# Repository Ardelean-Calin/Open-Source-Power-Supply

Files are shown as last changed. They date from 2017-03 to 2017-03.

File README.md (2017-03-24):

# Open-Source-Power-Supply
An open source benchtop power supply that's good enough for most purposes.

The case was **3D printed** using a [Monoprice Select Mini](https://www.monoprice.com/product?p_id=15365) with wood PLA
for the front and back panels and green PLA for the top and bottom parts of the case.

The 3D designs were generated using [Heartman's Ultimate Box Maker](http://www.thingiverse.com/thing:1264391) and 
[Steve Colley's Parametric Potentiometer Knob](http://www.thingiverse.com/thing:20513).

## Characteristics
- **Input Voltage:** Up to 19V without fan
- **Output Voltage:** 0-12V
- **Output Current:** 0-600mA (see Note)
- Adjustable current limit

**Note:** Current can go up to 800mA by replacing the five 10 Ohm resistors with five 5 Ohm resistors. One should also double the gain of the differential amplifier in this case, so as to display voltage and current correctly.

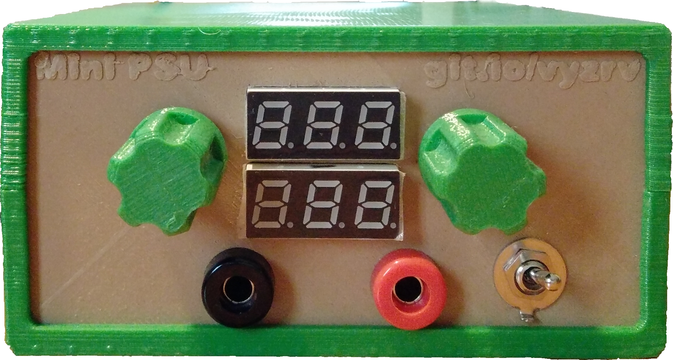
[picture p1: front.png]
Power Supply Front

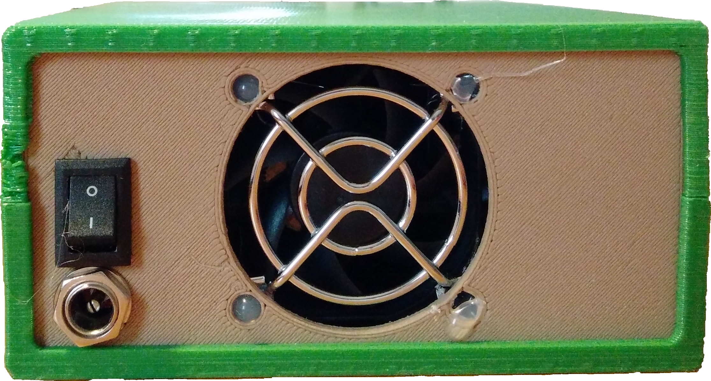
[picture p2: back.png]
Power Supply Back

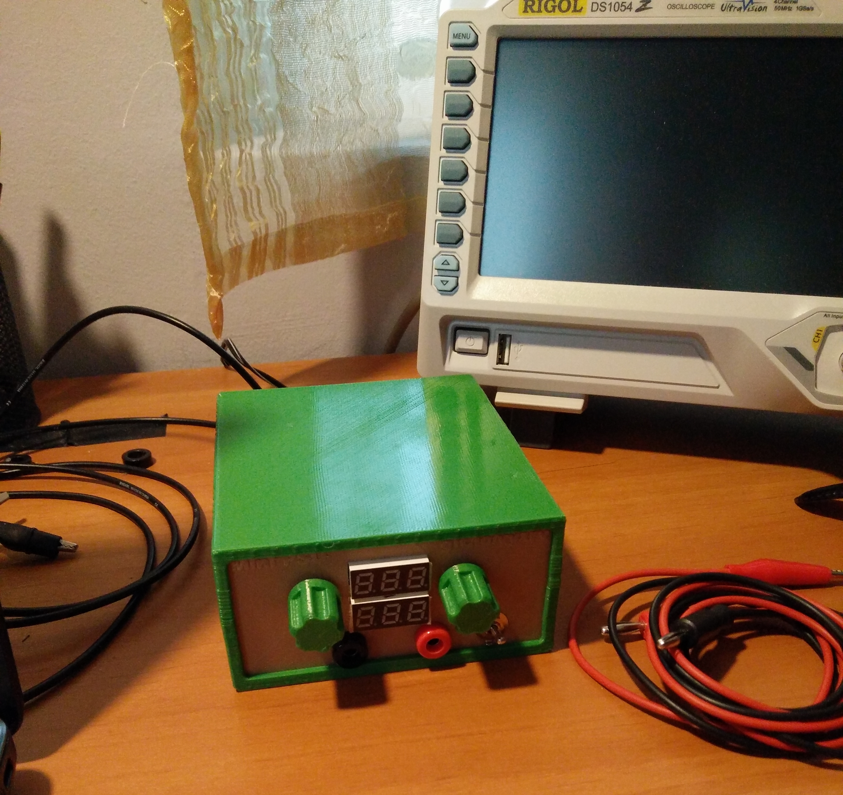
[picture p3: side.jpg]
Power Supply Side


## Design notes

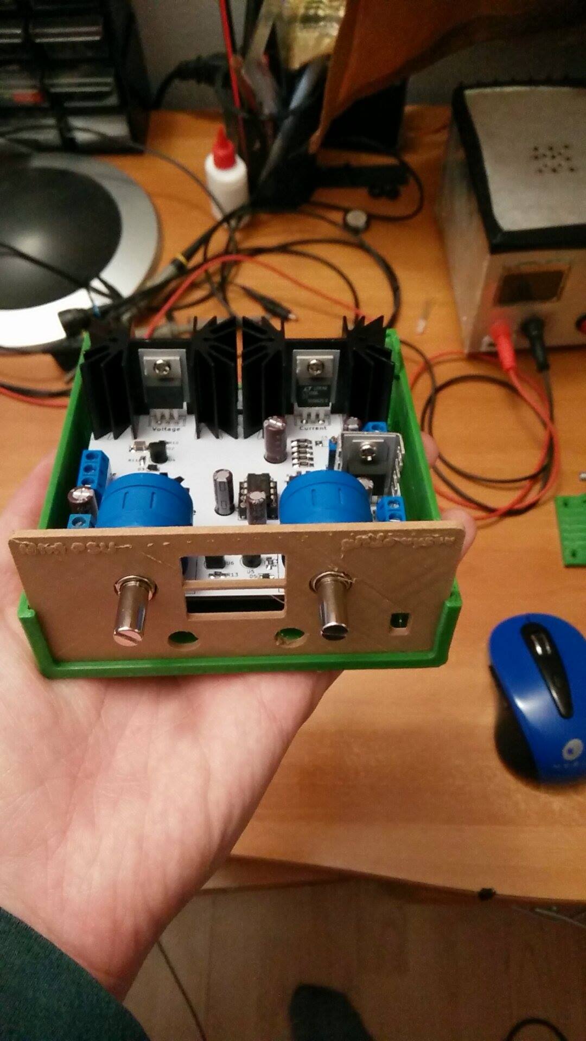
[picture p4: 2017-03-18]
inside.jpg

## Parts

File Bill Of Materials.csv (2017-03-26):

Id | Designator | Package | Quantity | Designation | Supplier and ref
1 | C1,C6,C7,C8 | CP_Radial_D5.0mm_P2.00mm | 4 | 10u
2 | C2 | CP_Radial_D6.3mm_P2.50mm | 1 | 47uF electro
3 | C3 | CP_Radial_D6.3mm_P2.50mm | 1 | 47u
4 | C4 | C_1210_HandSoldering | 1 | 4.7u
5 | C9 | C_0805_HandSoldering | 1 | 0.1u
6 | D1,D2,D3,D9,D10 | D_SOD-323_HandSoldering | 5 | 1N5819
7 | D4,D5,D6,D7,D8 | D_SOD-323_HandSoldering | 5 | 1N4448
8 | HS1,HS2 | Heatsink_Fischer_SK129-STS_42x25mm_2xDrill2.5mm | 2 | Heatsink
9 | HS3 | TO220-Small-16mmx8mm | 1 | Heatsink
10 | J1 | bornier2 | 1 | Input Voltage
11 | J2 | bornier2 | 1 | Output Voltage
12 | J3 | bornier3 | 1 | Voltage Meter
13 | J4 | bornier3 | 1 | Current Meter
14 | R1,R2 | R_0805_HandSoldering | 2 | 50k
15 | R3,R4 | R_0805_HandSoldering | 2 | 10k
16 | R10 | R_0805_HandSoldering | 1 | 1k
17 | R11,R13 | R_0805_HandSoldering | 2 | 15
18 | R12 | R_0805_HandSoldering | 1 | 33
19 | R14 | R_0805_HandSoldering | 1 | 330
20 | RV1 | Potentiometer_Trimmer_Bourns_3296W | 1 | 100 (multiturn)
21 | RV2,RV3 | Potentiometer-3596S-10k-Pot | 2 | 10k
22 | U1 | DIP-8_W7.62mm_Socket_LongPads | 1 | LT1013
23 | U2 | TO-220 | 1 | LT1086
24 | U3 | TO-220 | 1 | LM1117-ADJ
25 | U4,U5,U6 | TO-92_Inline_Narrow_Oval | 3 | LM334Z
26 | U7 | DIP-8_W7.62mm_Socket_LongPads | 1 | ICL7660
27 | U8 | TO-220 | 1 | LM7812CT
28 | R5,R6,R7,R8,R9 | R_1206_HandSoldering | 5 | 10
29 | HA40101V4-000U-999 | Fan: DC; axial; 12VDC; 40x40x10mm; 9m3/h; 18.2dBA | 1 | http://bit.ly/2nCJSI9
30 | R1-22-B | 4mm Banana Socket - Black | 1 | http://bit.ly/2nkKlNd
31 | R1-22-R | 4mm Banana Socket - Red | 1 | http://bit.ly/2n6f92k
32 | Voltmeter | Green Three line panel Voltmeter 0-100VDC | 2 | http://bit.ly/2n6a61O
33 | TSSM1022A1 | Switch: toggle; 2-position; SPDT; ON-ON; 1A/250VAC; Cutout: Ø5mm | 1 | http://bit.ly/2nCCyMR
34 | FG-04A | Fan guard 40mm | 1 | http://bit.ly/2nkV2z9
35 | RSSM1011C3BK | Rocker switch; 2-position; SPST; ON-OFF; 1A/250VAC | 1 | http://bit.ly/2nXvFq7
36 | DC socket. See back panel model |  | 1

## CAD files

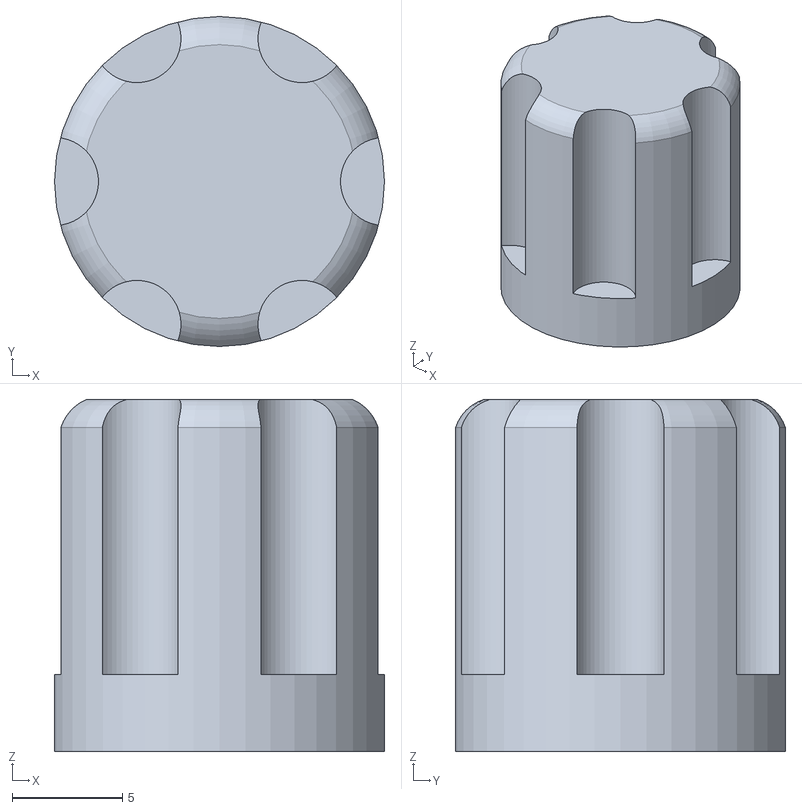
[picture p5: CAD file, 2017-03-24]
3D Printed Case/STLs/knob.stl
15.0 x 15.0 x 16.0

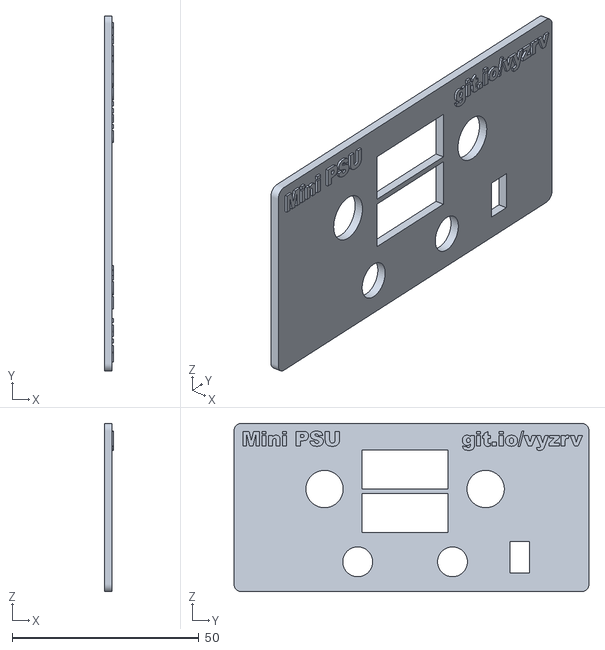
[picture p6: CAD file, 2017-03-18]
3D Printed Case/STLs/panel_front.stl
2.50 x 95.1 x 45.1

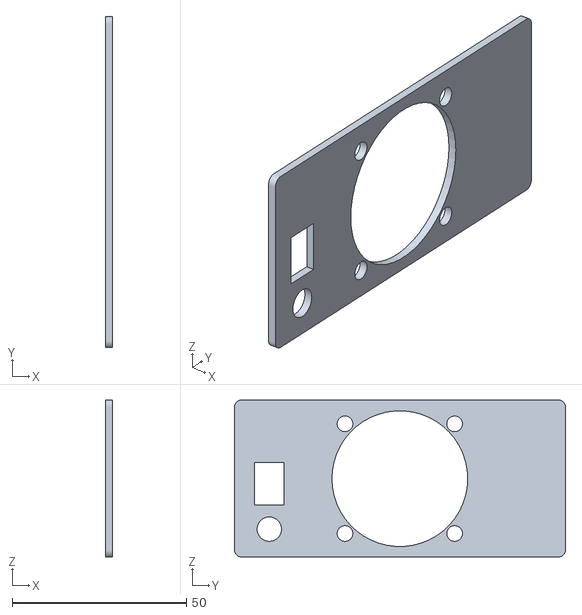
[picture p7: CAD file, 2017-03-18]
3D Printed Case/STLs/back_panel.stl
2.00 x 95.1 x 45.1

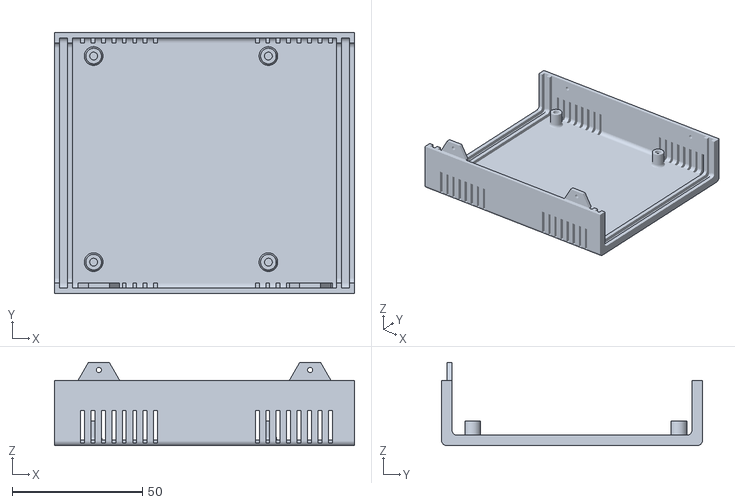
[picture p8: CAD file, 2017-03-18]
3D Printed Case/STLs/U_Box_Bottom.stl
115.0 x 100.0 x 31.9

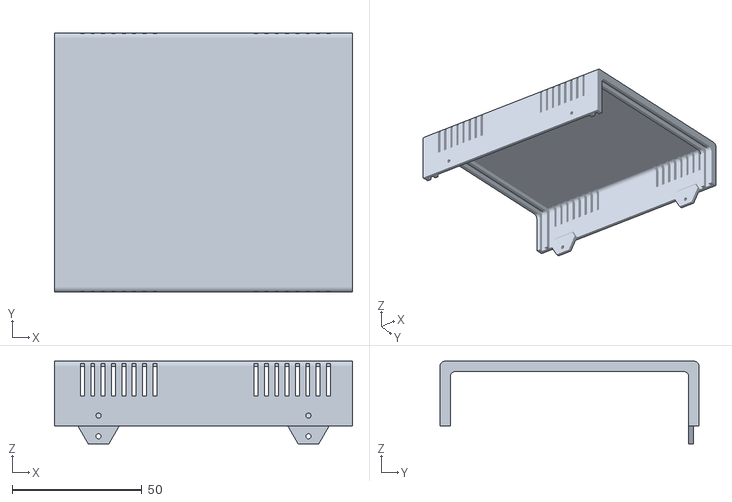
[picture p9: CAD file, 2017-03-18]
3D Printed Case/STLs/U_Box_Top.stl
115.0 x 100.0 x 31.9

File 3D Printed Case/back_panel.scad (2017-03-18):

/*//////////////////////////////////////////////////////////////////
              -    FB Aka Heartman/Hearty 2016     -                   
              -   http://heartygfx.blogspot.com    -                  
              -       OpenScad Parametric Box      -                     
              -         CC BY-NC 3.0 License       -                      
////////////////////////////////////////////////////////////////////                                                                                                             
12/02/2016 - Fixed minor bug 
28/02/2016 - Added holes ventilation option                    
09/03/2016 - Added PCB feet support, fixed the shell artefact on export mode. 

*/////////////////////////// - Info - //////////////////////////////

// All coordinates are starting as integrated circuit pins.
// From the top view :

//   CoordD           <---       CoordC
//                                 ^
//                                 ^
//                                 ^
//   CoordA           --->       CoordB


////////////////////////////////////////////////////////////////////


////////// - Paramètres de la boite - Box parameters - /////////////

/* [Box dimensions] */
// - Longueur - Length  
  Length        = 110;       
// - Largeur - Width
  Width         = 100;                     
// - Hauteur - Height  
  Height        = 50;  
// - Epaisseur - Wall thickness  
  Thick         = 2;//[2:5]  
  
/* [Box options] */
// - Diamètre Coin arrondi - Filet diameter  
  Filet         = 2;//[0.1:12] 
// - lissage de l'arrondi - Filet smoothness  
  Resolution    = 50;//[1:100] 
// - Tolérance - Tolerance (Panel/rails gap)
  m             = 0.9;
// Pieds PCB - PCB feet (x4) 
  PCBFeet       = 0;// [0:No, 1:Yes]
// - Decorations to ventilation holes
  Vent          = 1;// [0:No, 1:Yes]
// - Decoration-Holes width (in mm)
  Vent_width    = 1.5;   


  
/* [PCB_Feet] */
//All dimensions are from the center foot axis

// - Coin bas gauche - Low left corner X position
PCBPosX         = 7;
// - Coin bas gauche - Low left corner Y position
PCBPosY         = 6;
// - Longueur PCB - PCB Length
PCBLength       = 90;
// - Largeur PCB - PCB Width
PCBWidth        = 90;
// - Heuteur pied - Feet height
FootHeight      = 17.7;
// - Diamètre pied - Foot diameter
FootDia         = 8;
// - Diamètre trou - Hole diameter
FootHole        = 3;  
  

/* [STL element to export] */
//Coque haut - Top shell
TShell          = 0;// [0:No, 1:Yes]
//Coque bas- Bottom shell
BShell          = 0;// [0:No, 1:Yes]
//Panneau avant - Front panel
FPanL           = 1;// [0:No, 1:Yes]
//Panneau arrière - Back panel  
BPanL           = 0;// [0:No, 1:Yes]


  
/* [Hidden] */
// - Couleur coque - Shell color  
Couleur1        = "Orange";       
// - Couleur panneaux - Panels color    
Couleur2        = "OrangeRed";    
// Thick X 2 - making decorations thicker if it is a vent to make sure they go through shell
Dec_Thick       = Vent ? Thick*2 : Thick; 
// - Depth decoration
Dec_size        = Vent ? Thick*2 : 0.8;





/////////// - Boitier générique bord arrondis - Generic rounded box - //////////

module RoundBox($a=Length, $b=Width, $c=Height){// Cube bords arrondis
                    $fn=Resolution;            
                    translate([0,Filet,Filet]){  
                    minkowski (){                                              
                        cube ([$a-(Length/2),$b-(2*Filet),$c-(2*Filet)], center = false);
                        rotate([0,90,0]){    
                        cylinder(r=Filet,h=Length/2, center = false);
                            } 
                        }
                    }
                }// End of RoundBox Module

      
////////////////////////////////// - Module Coque/Shell - //////////////////////////////////         

module Coque(){//Coque - Shell  
    Thick = Thick*2;  
    difference(){    
        difference(){//sides decoration
            union(){    
                     difference() {//soustraction de la forme centrale - Substraction Fileted box
                      
                        difference(){//soustraction cube median - Median cube slicer
                            union() {//union               
                            difference(){//Coque    
                                RoundBox();
                                translate([Thick/2,Thick/2,Thick/2]){     
                                        RoundBox($a=Length-Thick, $b=Width-Thick, $c=Height-Thick);
                                        }
                                        }//Fin diff Coque                            
                                difference(){//largeur Rails        
                                     translate([Thick+m,Thick/2,Thick/2]){// Rails
                                          RoundBox($a=Length-((2*Thick)+(2*m)), $b=Width-Thick, $c=Height-(Thick*2));
                                                          }//fin Rails
                                     translate([((Thick+m/2)*1.55),Thick/2,Thick/2+0.1]){ // +0.1 added to avoid the artefact
                                          RoundBox($a=Length-((Thick*3)+2*m), $b=Width-Thick, $c=Height-Thick);
                                                    }           
                                                }//Fin largeur Rails
                                    }//Fin union                                   
                               translate([-Thick,-Thick,Height/2]){// Cube à soustraire
                                    cube ([Length+100, Width+100, Height], center=false);
                                            }                                            
                                      }//fin soustraction cube median - End Median cube slicer
                               translate([-Thick/2,Thick,Thick]){// Forme de soustraction centrale 
                                    RoundBox($a=Length+Thick, $b=Width-Thick*2, $c=Height-Thick);       
                                    }                          
                                }                                          


                difference(){// wall fixation box legs
                    union(){
                        translate([3*Thick +5,Thick,Height/2]){
                            rotate([90,0,0]){
                                    $fn=6;
                                    cylinder(d=16,Thick/2);
                                    }   
                            }
                            
                       translate([Length-((3*Thick)+5),Thick,Height/2]){
                            rotate([90,0,0]){
                                    $fn=6;
                                    cylinder(d=16,Thick/2);
                                    }   
                            }

                        }
                            translate([4,Thick+Filet,Height/2-57]){   
                             rotate([45,0,0]){
                                   cube([Length,40,40]);    
                                  }
                           }
                           translate([0,-(Thick*1.46),Height/2]){
                                cube([Length,Thick*2,10]);
                           }
                    } //Fin fixation box legs
            }

        union(){// outbox sides decorations
            
            for(i=[0:Thick:Length/4]){

                // Ventilation holes part code submitted by Ettie - Thanks ;) 
                    translate([10+i,-Dec_Thick+Dec_size,1]){
                    cube([Vent_width,Dec_Thick,Height/4]);
                    }
                    translate([(Length-10) - i,-Dec_Thick+Dec_size,1]){
                    cube([Vent_width,Dec_Thick,Height/4]);
                    }
                    translate([(Length-10) - i,Width-Dec_size,1]){
                    cube([Vent_width,Dec_Thick,Height/4]);
                    }
                    translate([10+i,Width-Dec_size,1]){
                    cube([Vent_width,Dec_Thick,Height/4]);
                    }
  
                
                    }// fin de for
               // }
                }//fin union decoration
            }//fin difference decoration
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

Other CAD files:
3D Printed Case/front_panel.scad
3D Printed Case/full_enclosure.scad
3D Printed Case/U_Box_V103.scad
3D Printed Case/potknob_parametric.scad

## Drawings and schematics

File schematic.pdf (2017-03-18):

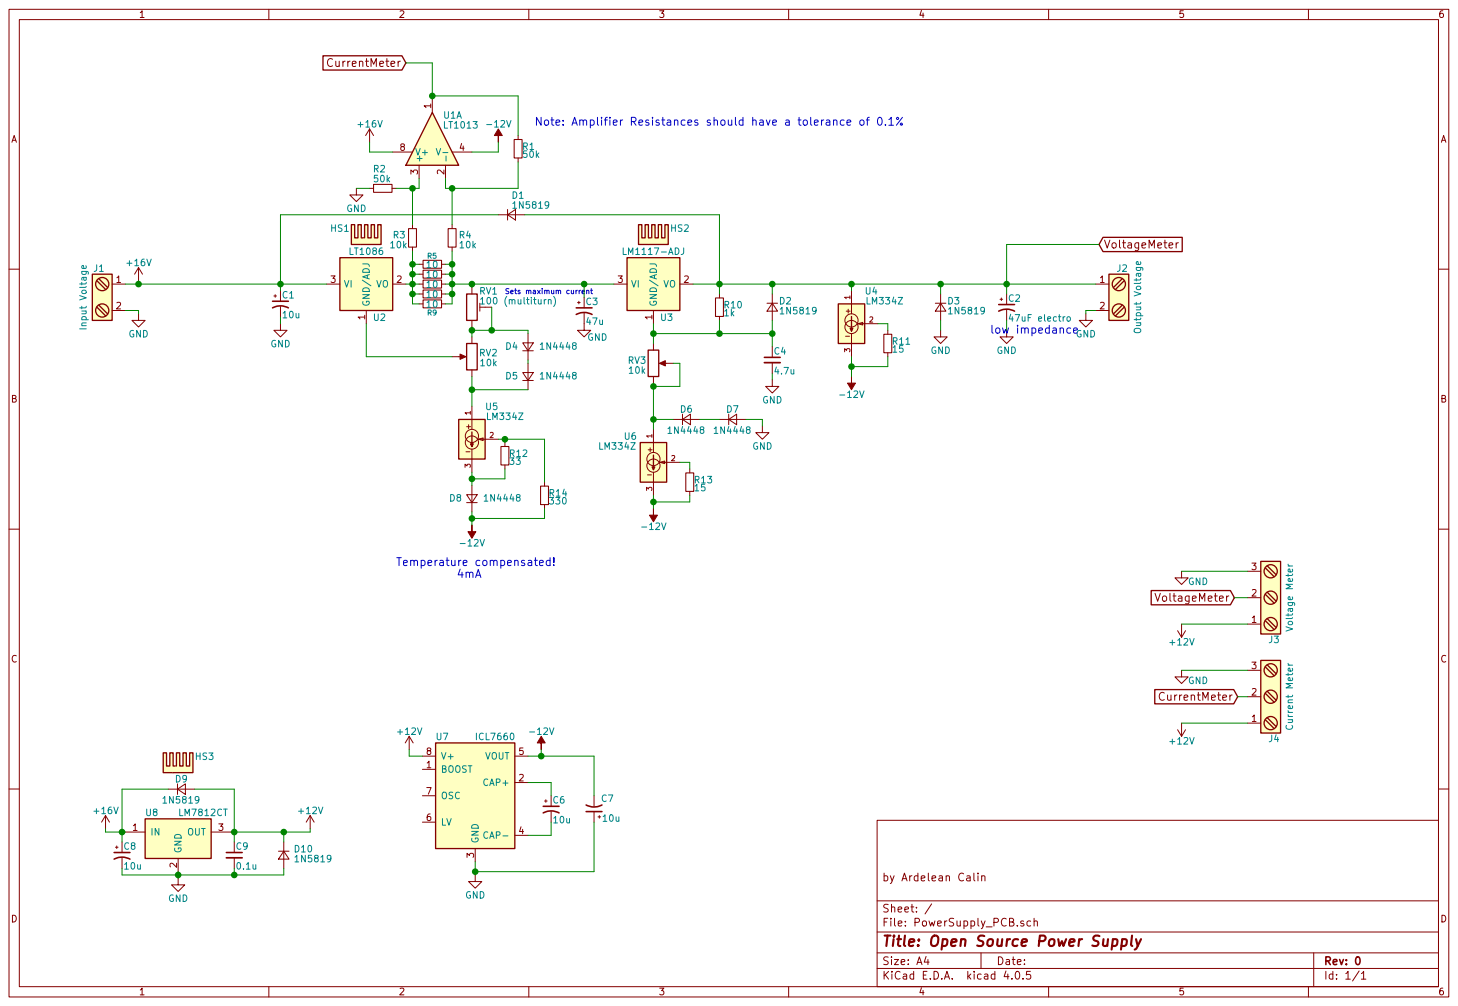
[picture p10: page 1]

Id: 1/1 Title: Open Source Power Supply

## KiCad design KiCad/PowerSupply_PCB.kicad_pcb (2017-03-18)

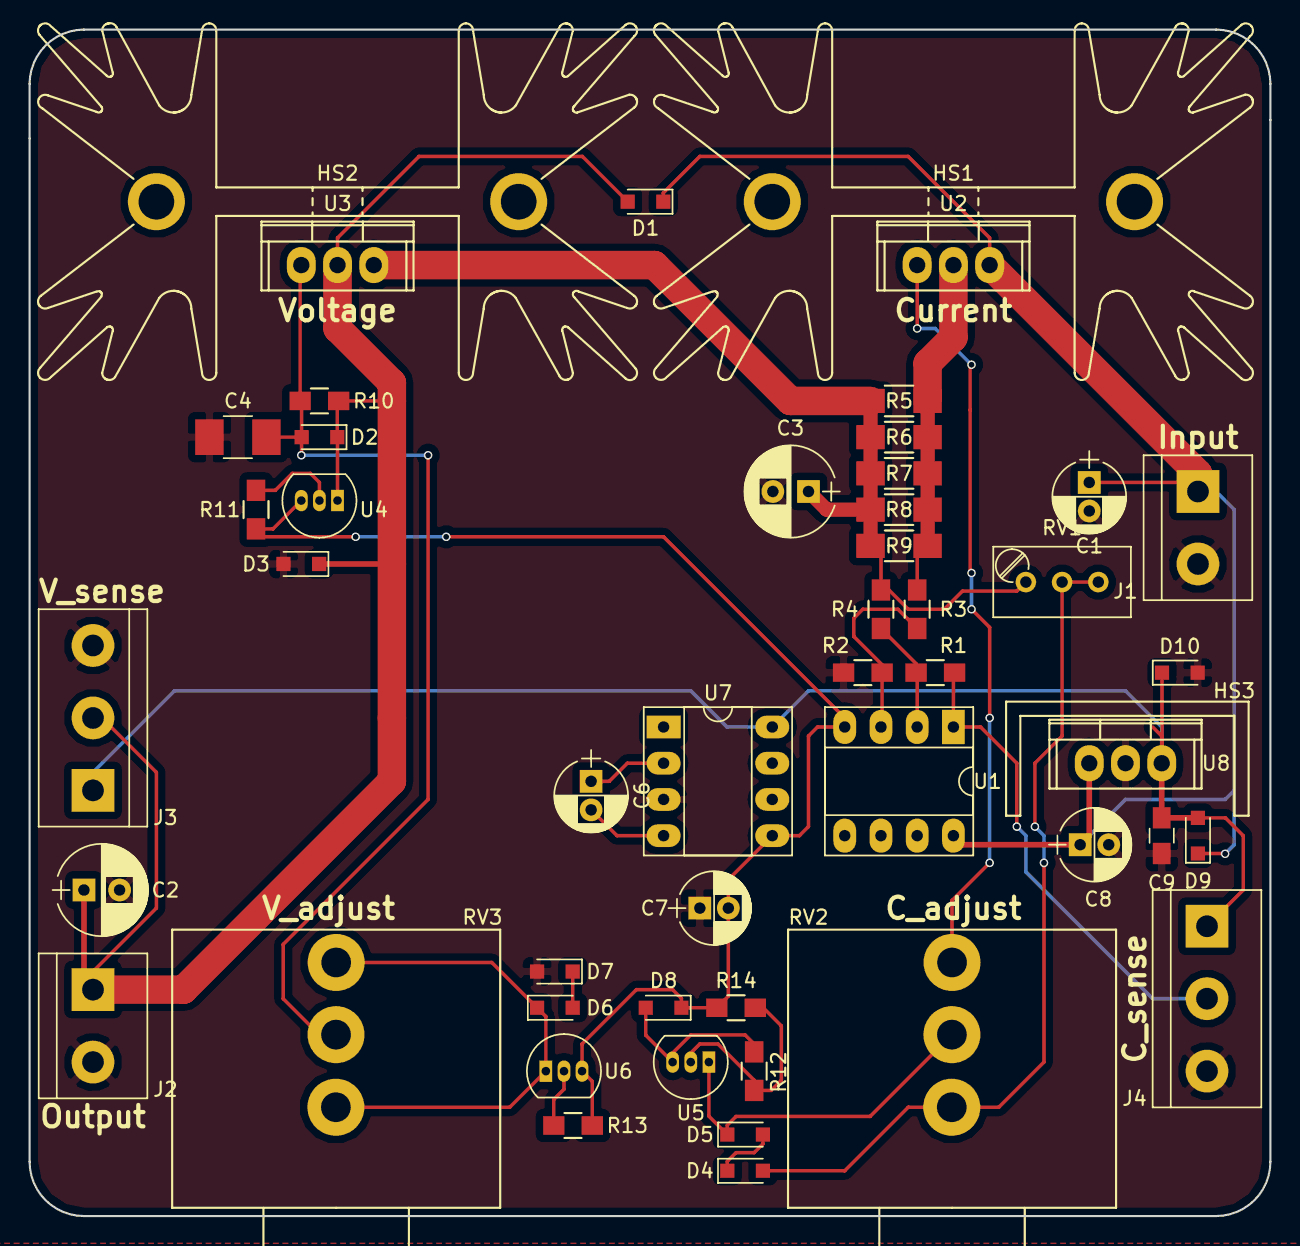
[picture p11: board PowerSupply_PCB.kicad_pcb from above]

Board: 2 copper layers, 87.0 x 83.2 mm, 50 parts (0 on the bottom side), 23 nets.

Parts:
C1, C6, C7, C8: 10u; CP_Radial_D5.0mm_P2.00mm
C2: 47uF electro; CP_Radial_D6.3mm_P2.50mm
C3: 47u; CP_Radial_D6.3mm_P2.50mm
C4: 4.7u; C_1210_HandSoldering
C9: 0.1u; C_0805_HandSoldering
D1, D2, D3, D9, D10: 1N5819; D_SOD-323_HandSoldering
D4, D5, D6, D7, D8: 1N4448; D_SOD-323_HandSoldering
HS1, HS2: Heatsink; Heatsink_Fischer_SK129-STS_42x25mm_2xDrill2.5mm
HS3: Heatsink; TO220-Small-16mmx8mm
J1: Input Voltage; bornier2
J2: Output Voltage; bornier2
J3: Voltage Meter; bornier3
J4: Current Meter; bornier3
R1, R2: 50k; R_0805_HandSoldering
R3, R4: 10k; R_0805_HandSoldering
R5, R6, R7, R8, R9: 10; R_1206_HandSoldering
R10: 1k; R_0805_HandSoldering
R11, R13: 15; R_0805_HandSoldering
R12: 33; R_0805_HandSoldering
R14: 330; R_0805_HandSoldering
RV1: 100 (multiturn); Potentiometer_Trimmer_Bourns_3296W
RV2, RV3: 10k; Potentiometer-3596S-10k-Pot
U1: LT1013; DIP-8_W7.62mm_Socket_LongPads
U2: LT1086; TO-220
U3: LM1117-ADJ; TO-220
U4, U5, U6: LM334Z; TO-92_Inline_Narrow_Oval
U7: ICL7660; DIP-8_W7.62mm_Socket_LongPads
U8: LM7812CT; TO-220

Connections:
+12V: C9.1, D9.2, D10.1, J3.1, J4.1, U7.8, U8.3
+16V: C1.1, C8.1, D1.1, D9.1, J1.1, U1.8, U2.3, U8.1
-12V: C7.2, D8.1, R11.2, R13.2, R14.2, U1.4, U4.3, U6.3, U7.5
CurrentMeter: J4.2, R1.1, U1.1
GND: C1.2, C2.2, C3.2, C4.2, C7.1, C8.2, C9.2, D3.2, D7.2, D10.2, J1.2, J2.2, J3.3, J4.3, R2.2, U7.3, U8.2
unnamed: C3.1, R4.2, R5.1, R6.1, R7.1, R8.1, R9.1, RV1.1, U3.3
unnamed: C4.1, D2.2, R10.2, RV3.1, U3.1
unnamed: C6.1, U7.2
unnamed: C6.2, U7.4
unnamed: D4.1, D5.2
unnamed: D4.2, RV1.2, RV1.3, RV2.3
unnamed: D5.1, RV2.1, U5.1
unnamed: D6.1, RV3.2, RV3.3, U6.1
unnamed: D6.2, D7.1
unnamed: D8.2, R12.2, U5.3
unnamed: R1.2, R4.1, U1.2
unnamed: R2.1, R3.1, U1.3
unnamed: R3.2, R5.2, R6.2, R7.2, R8.2, R9.2, U2.2
unnamed: R11.1, U4.2
unnamed: R12.1, R14.1, U5.2
unnamed: R13.1, U6.2
unnamed: RV2.2, U2.1
VoltageMeter: C2.1, D1.2, D2.1, D3.1, J2.1, J3.2, R10.1, U3.2, U4.1

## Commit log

2017-03-18 Added the only photo of the complete PCB that I had
    [Bill Of Materials.csv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]
2017-03-19 Update Bill Of Materials.csv
    [Bill Of Materials.csv]
2017-03-24 Added potentiometer knob design files
    [knob.stl, potknob_parametric.scad]
2017-03-26 Update Bill Of Materials.csv
    Added items which are not found on the PCB, but are needed in order to finish the build.
    [Bill Of Materials.csv]
